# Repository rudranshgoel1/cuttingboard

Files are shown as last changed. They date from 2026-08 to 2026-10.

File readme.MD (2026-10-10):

# RP2040 Devboard
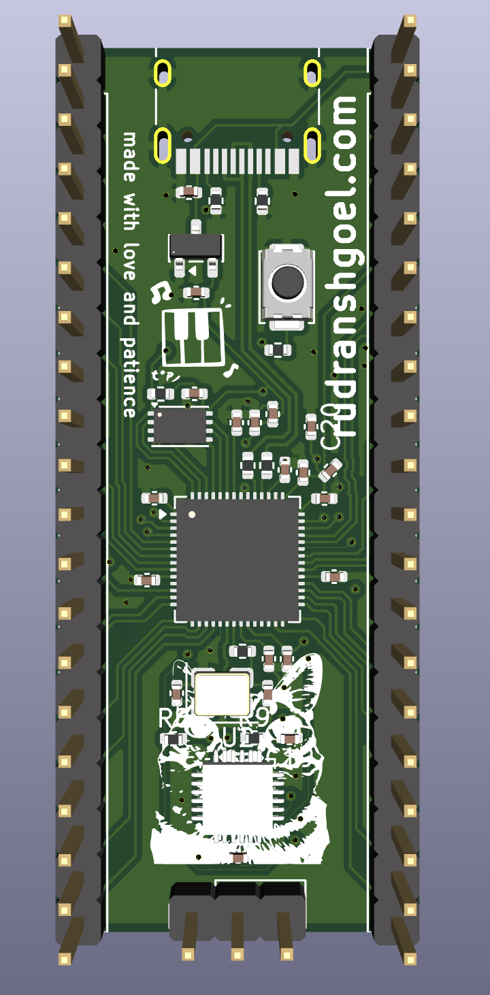
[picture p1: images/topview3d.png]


### Why did I make it?
bcz i need more hardware projects in my portfolio and also because it seemed like a fun hardware project which was not at all beginner friendly but still pretty interesting.

### What was the hardest part about this ?
routing. routing was hell. nevertheless, we did it.

### assembly?
going to hand solder each thing, if you want to do pcba (i can't due to budget reasons), go to the production folder and get the BOM and CPL for jlcpcb pcba service.

Features:

- rp2040 chip
- usb-c for power
- flash memory/storage
- crystal occilator
- built in accelerometer for cool shit
- Custom PCB Art (really cool)
- led

### Schematic
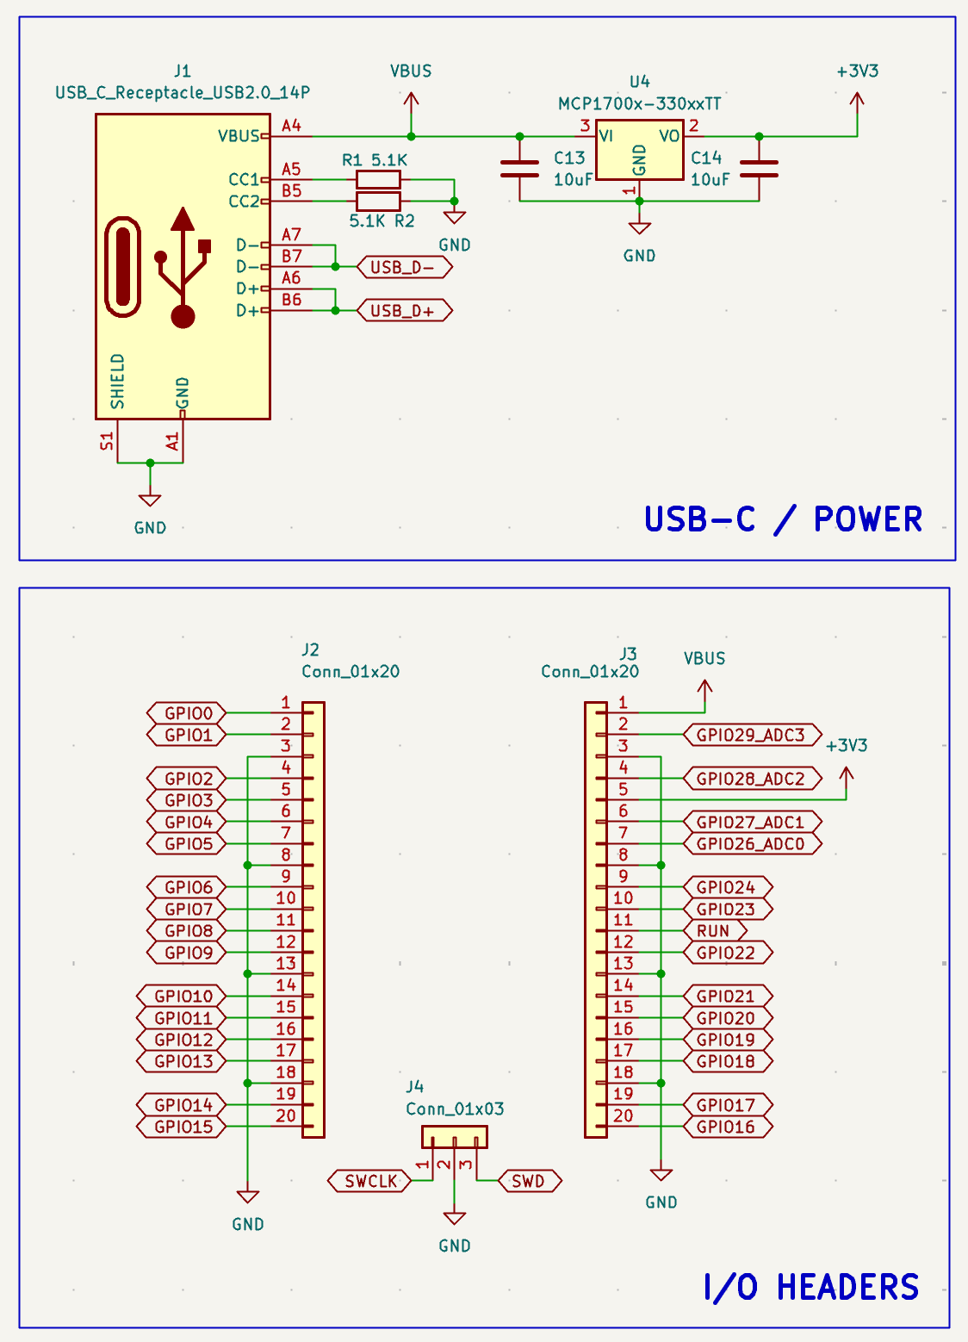
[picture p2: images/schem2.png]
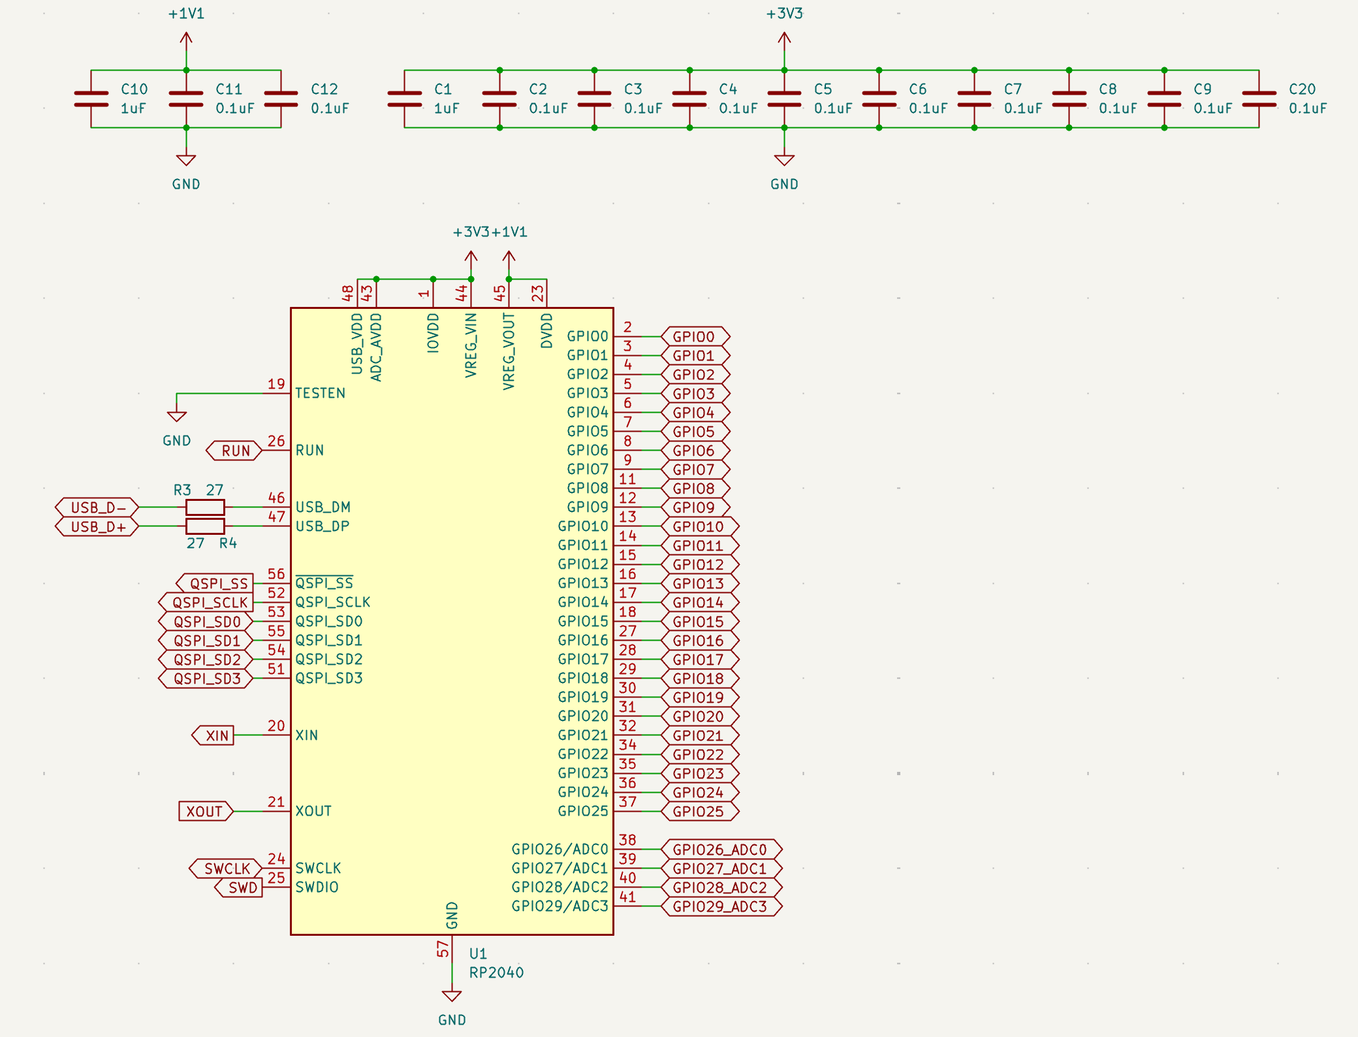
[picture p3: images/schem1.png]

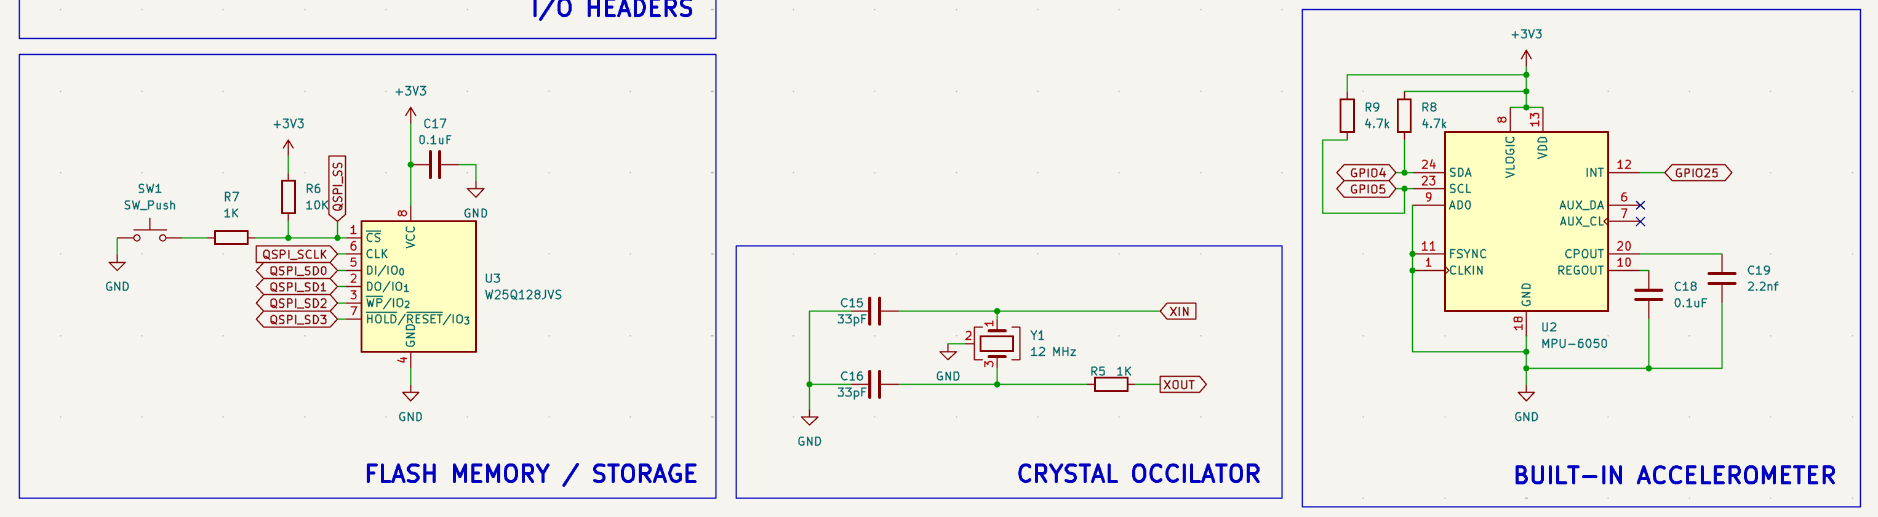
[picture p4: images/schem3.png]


### PCB 
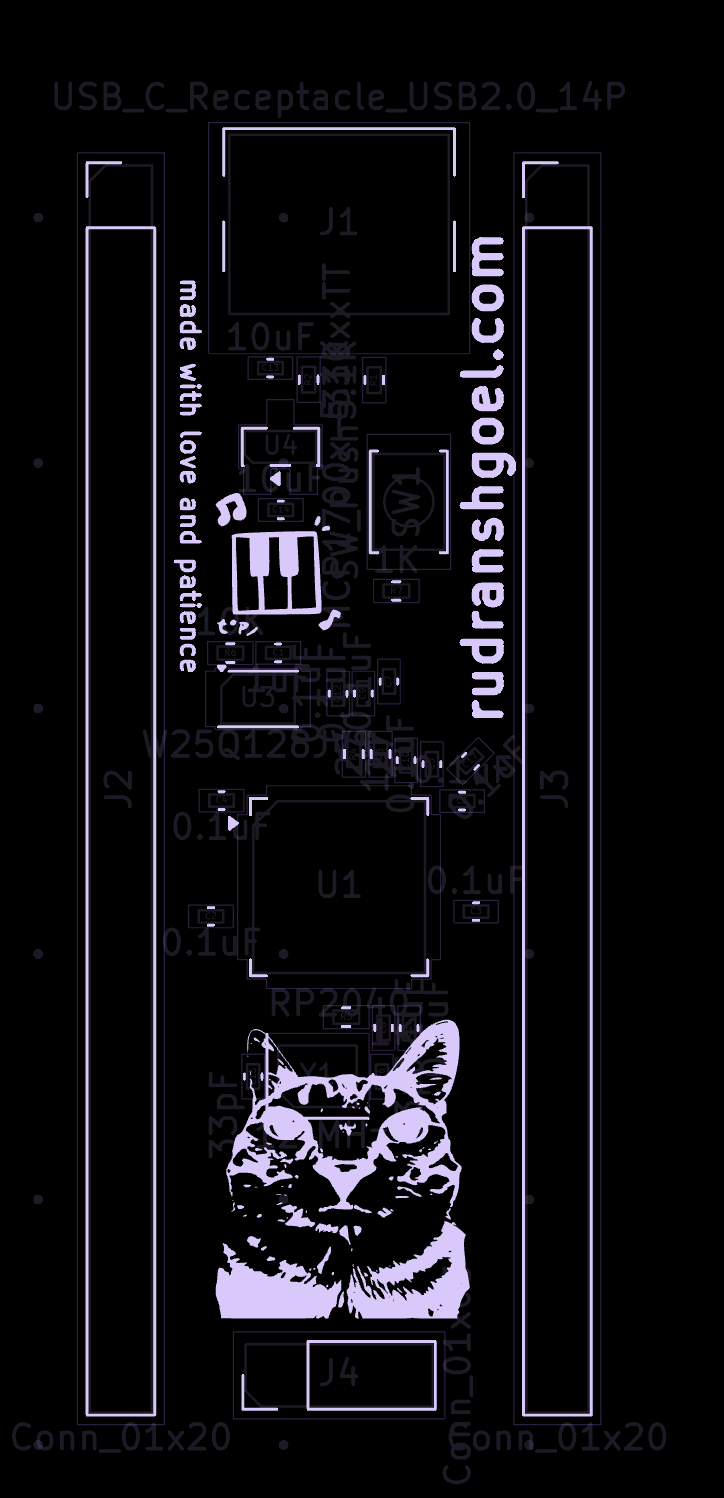
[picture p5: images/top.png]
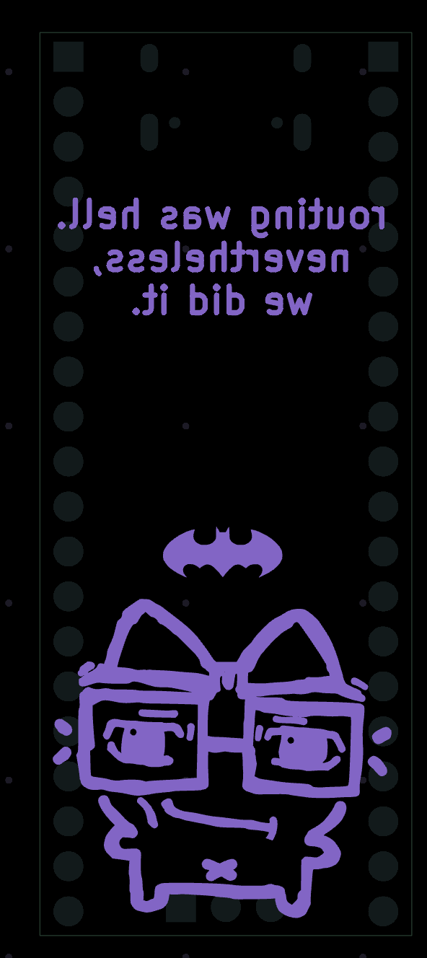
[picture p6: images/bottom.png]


### 3D view of all parts 
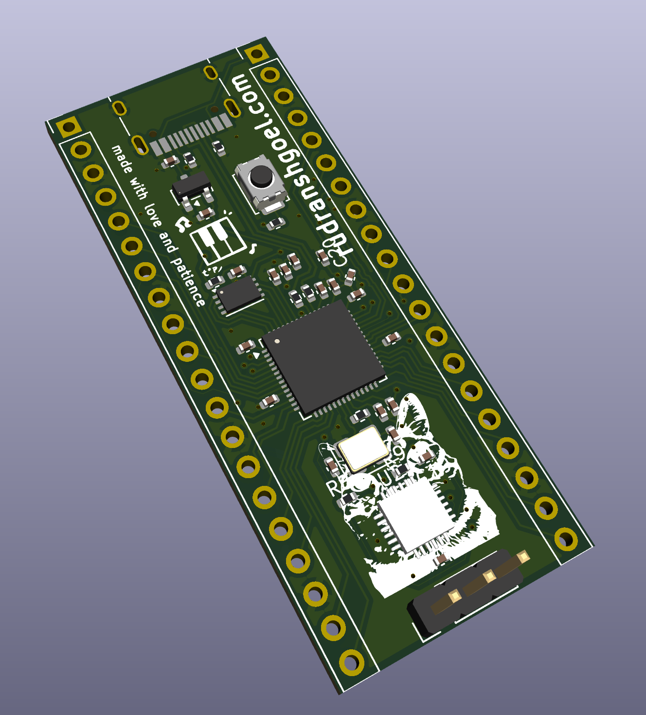
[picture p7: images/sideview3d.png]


## BOM

[BOM](BOM.csv)
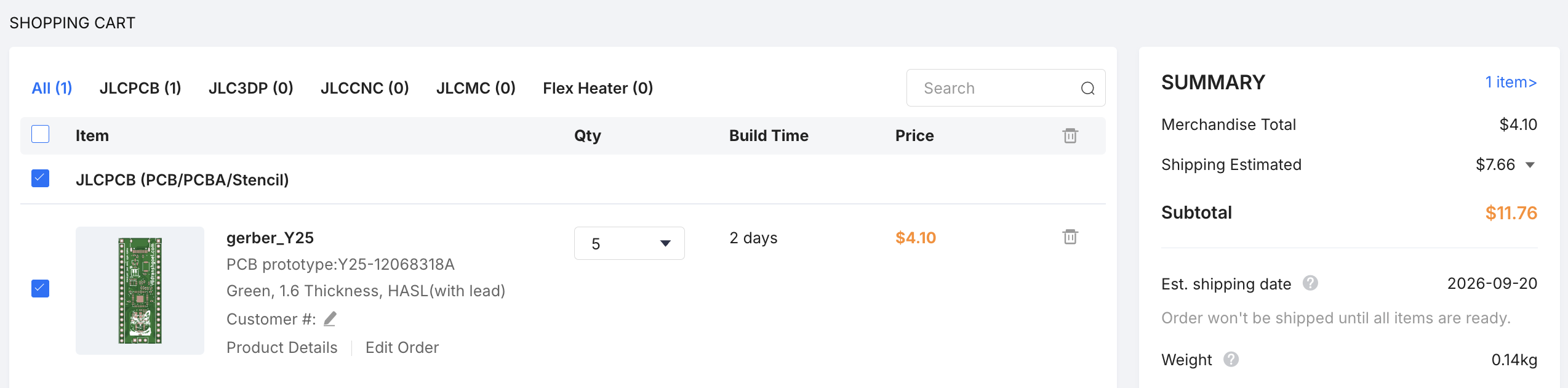
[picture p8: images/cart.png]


|Comment |Designator |Footprint |JLCPCB Part #|Price  |Source |
|---|---|---|---|---|---|
|1uF |C10,C1 |C_0402_1005Metric |C52923 |$0.2420|JLCPCB PCBA|
|MCP1700x-330xxTT |U4 |SOT-23 |C39051 |$2.0390|JLCPCB PCBA|
|33pF |C15,C16 |C_0402_1005Metric |C1562 |$0.1140|JLCPCB PCBA|
|1K |R7,R5 |R_0402_1005Metric |C11702 |$0.0780|JLCPCB PCBA|
|5.1K |R2,R1 |R_0402_1005Metric |C25905 |$0.0860|JLCPCB PCBA|
|12MHz |Y1 |Crystal_SMD_3225-4Pin_3.2x2.5mm |C9002 |$0.6629|JLCPCB PCBA|
|10uF |C13,C14 |C_0402_1005Metric |C19702 |$0.7000|JLCPCB PCBA|
|RP2040 |U1 |QFN-56-1EP_7x7mm_P0.4mm_EP3.2x3.2mm |C2040 |$4.9625|JLCPCB PCBA|
|0.1uF |C8,C17,C12,C4,C3,C5,C6,C2,C11,C7,C9|C_0402_1005Metric |C1525 |$0.3575|JLCPCB PCBA|
|W25Q128JVS |U3 |Winbond_USON-8-1EP_3x2mm_P0.5mm_EP0.2x1.6mm|C2843335 |$7.8700|JLCPCB PCBA|
|10K |R6 |R_0402_1005Metric |C25744 |$0.0380|JLCPCB PCBA|
|USB_C_Receptacle_USB2.0_14P|J1 |USB_C_Receptacle_HRO_TYPE-C-31-M-12 |C165948 |$0.9280|JLCPCB PCBA|
|27 |R4,R3 |R_0402_1005Metric |C25100 |$0.0704|JLCPCB PCBA|
|SW_Push |SW1 |SW_Push_SPST_NO_Alps_SKRK |C720477 |$0.5004|JLCPCB PCBA|

PCB Cost - $11.76 [ shipping included ]
Components Cost - $18.65

Final Price comes out to be 2,915.48 INR ($30.41)

## Total Pricing
(reviewers, i have a jlcpcb coupon for $15, so the pcb cost get's nullified, so the total cost for me is $18.65, but for others it would be the price given below)
The total price comes out to be 2,915.48 INR ($30.41) [ SHIPPING INCLUDED ]

I am going to hand solder all the components.

The pricing might slightly vary due to flash sales, and dollar market trends.

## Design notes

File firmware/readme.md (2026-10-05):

# firmware

- led on gpio0 blinks
- 500ms on and 500ms off

code is [here](firmware.ino)

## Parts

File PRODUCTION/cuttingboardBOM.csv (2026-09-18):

Id | Designator | Footprint | Quantity | Designation | Supplier and ref
1 | C1, C10 | C_0402_1005Metric | 2 | 1uF
2 | C2, C3, C4, C5, C6, C7, C8, C9, C11, C12, C17, C18, C20 | C_0402_1005Metric | 13 | 0.1uF
3 | C13, C14 | C_0402_1005Metric | 2 | 10uF
4 | C15, C16 | C_0402_1005Metric | 2 | 33pF
5 | C19 | C_0402_1005Metric | 1 | 2.2nf
6 | J1 | USB_C_Receptacle_HRO_TYPE-C-31-M-12 | 1 | USB_C_Receptacle_USB2.0_14P
7 | J2, J3 | PinHeader_1x20_P2.54mm_Vertical | 2 | Conn_01x20
8 | J4 | PinHeader_1x03_P2.54mm_Vertical | 1 | Conn_01x03
9 | R1, R2 | R_0402_1005Metric | 2 | 5.1K
10 | R3, R4 | R_0402_1005Metric | 2 | 27
11 | R5, R7 | R_0402_1005Metric | 2 | 1K
12 | R6 | R_0402_1005Metric | 1 | 10K
13 | R8, R9 | R_0402_1005Metric | 2 | 4.7k
14 | SW1 | SW_Push_SPST_NO_Alps_SKRK | 1 | SW_Push
15 | U1 | QFN-56-1EP_7x7mm_P0.4mm_EP3.2x3.2mm | 1 | RP2040
16 | U2 | InvenSense_QFN-24_4x4mm_P0.5mm | 1 | MPU-6050
17 | U3 | Winbond_USON-8-1EP_3x2mm_P0.5mm_EP0.2x1.6mm | 1 | W25Q128JVS
18 | U4 | SOT-23 | 1 | MCP1700x-330xxTT
19 | Y1 | Crystal_SMD_3225-4Pin_3.2x2.5mm | 1 | 12 MHz

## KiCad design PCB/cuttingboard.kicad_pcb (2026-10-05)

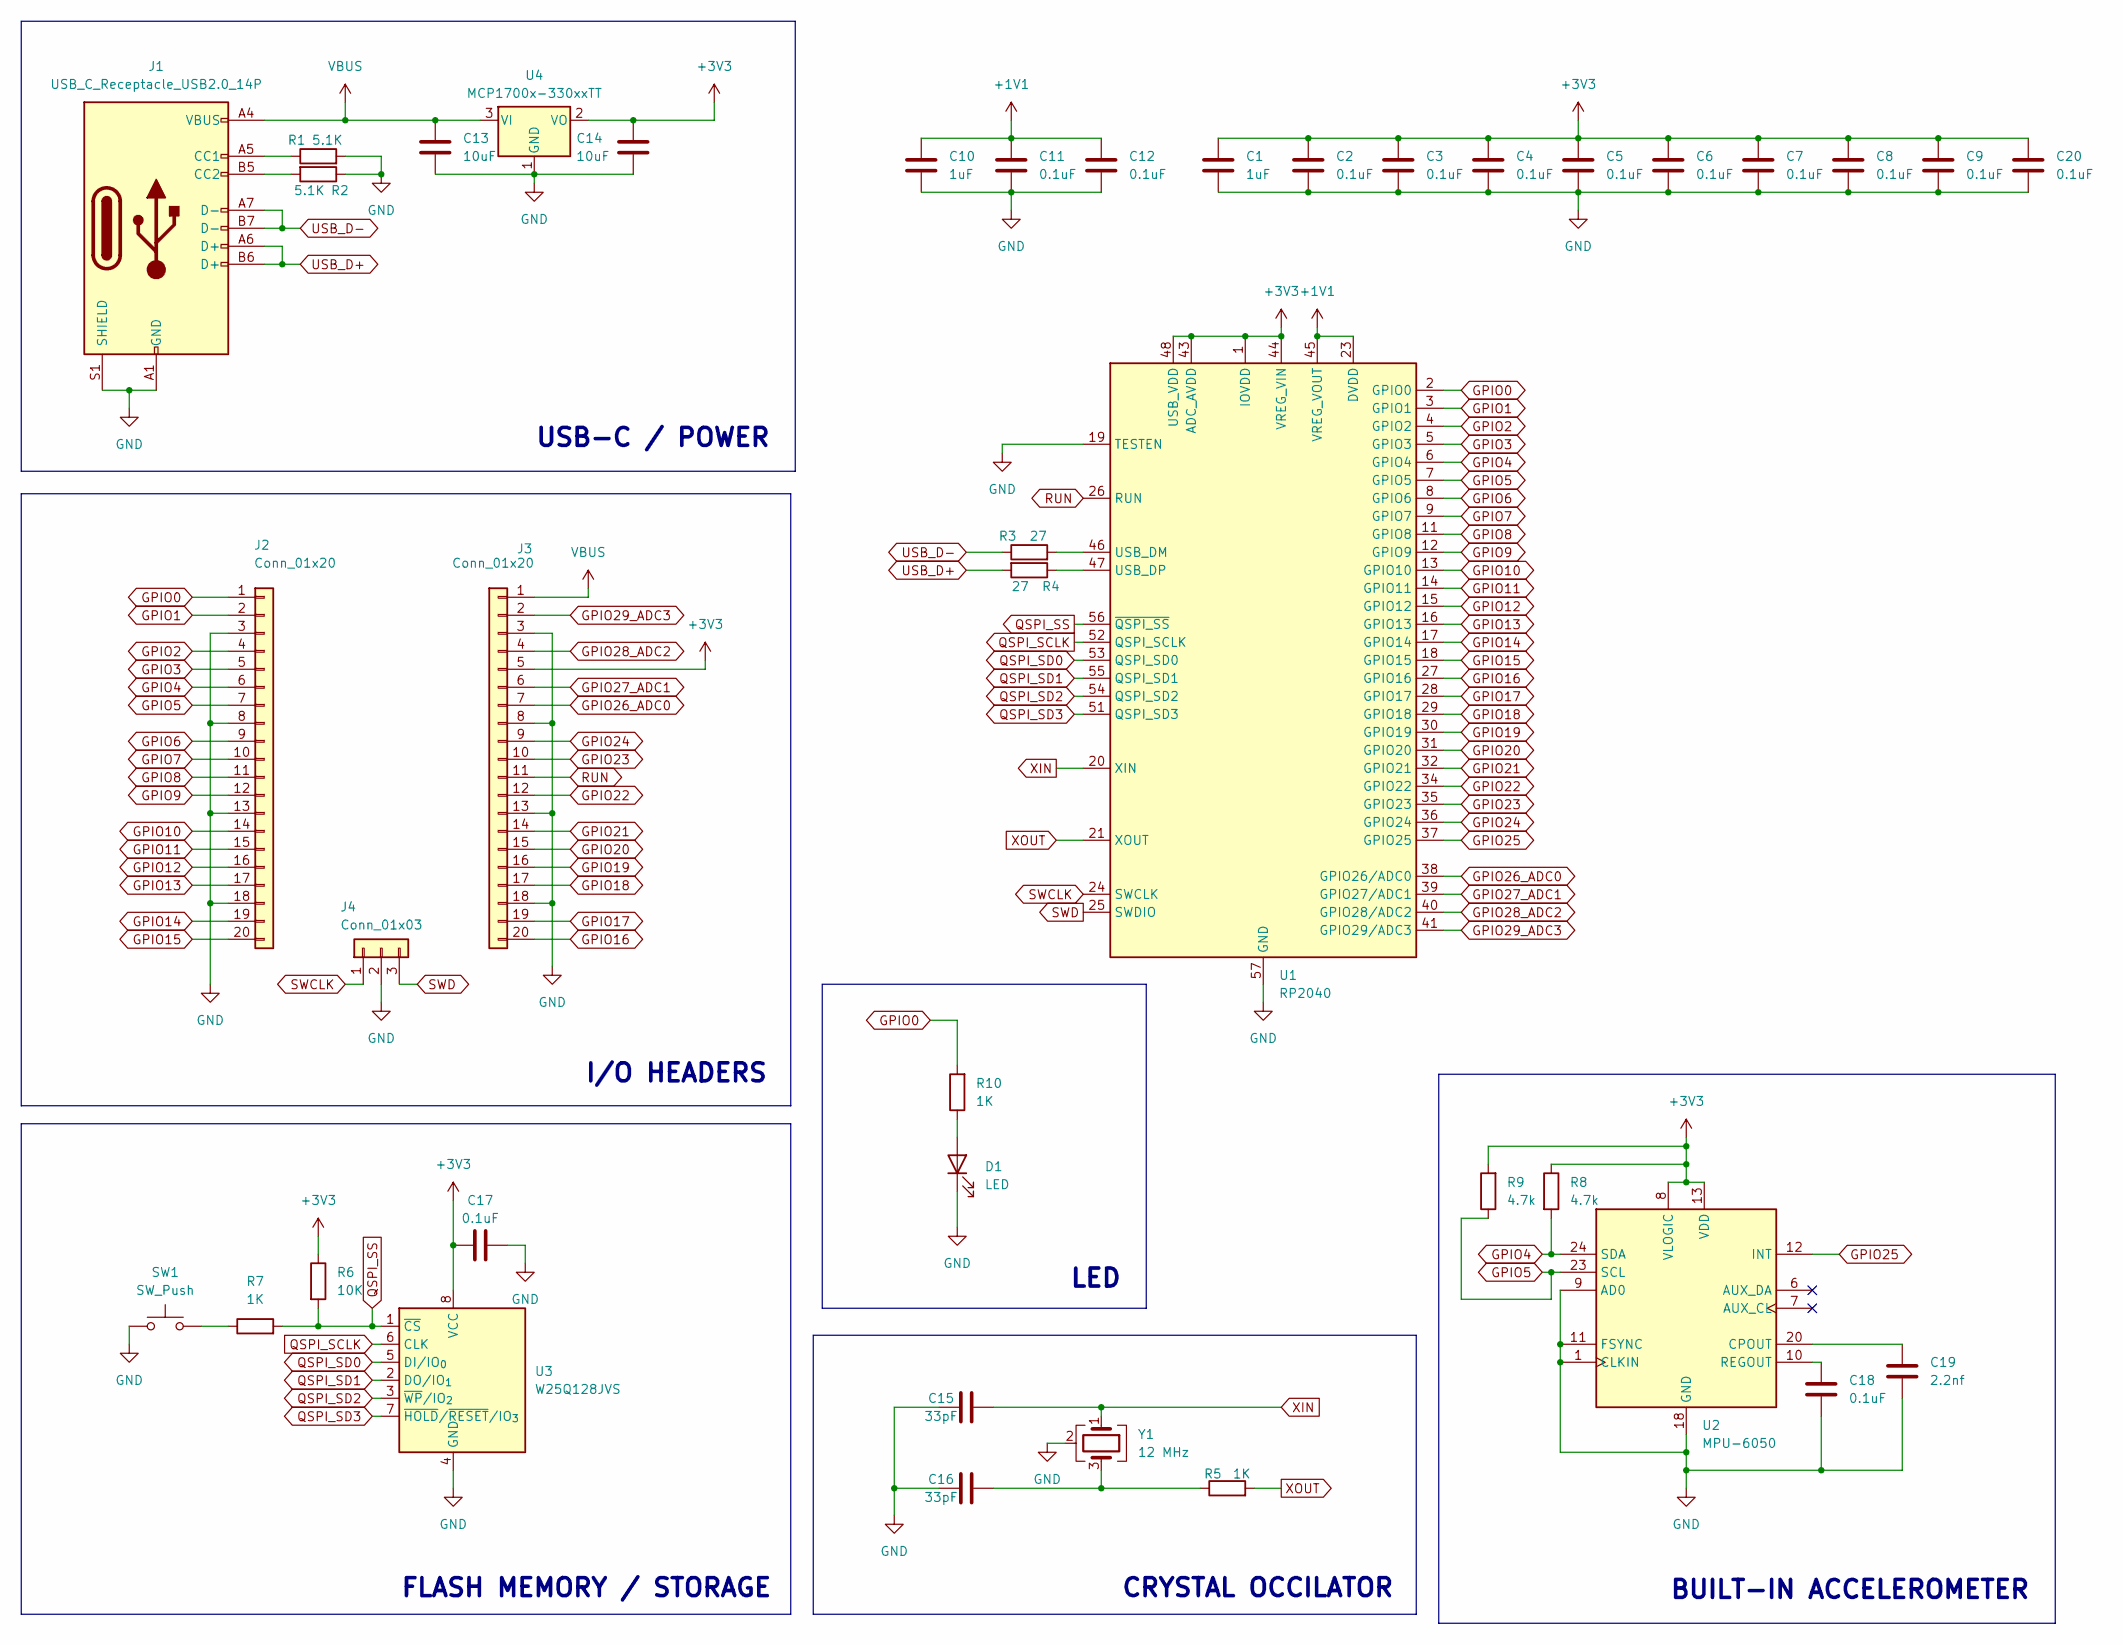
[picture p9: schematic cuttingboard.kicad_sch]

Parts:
C1, C10: 1uF; C_0402_1005Metric
C2, C3, C4, C5, C6, C7, C8, C9, C11, C12, C17, C18, C20: 0.1uF; C_0402_1005Metric
C13, C14: 10uF; C_0402_1005Metric
C15, C16: 33pF; C_0402_1005Metric
C19: 2.2nf; C_0402_1005Metric
D1: LED; LED_0805_2012Metric_Pad1.15x1.40mm_HandSolder
J1: USB_C_Receptacle_USB2.0_14P; USB_C_Receptacle_HRO_TYPE-C-31-M-12
J2, J3: Conn_01x20; PinHeader_1x20_P2.54mm_Vertical
J4: Conn_01x03; PinHeader_1x03_P2.54mm_Vertical
R1, R2: 5.1K; R_0402_1005Metric
R3, R4: 27; R_0402_1005Metric
R5, R7, R10: 1K; R_0402_1005Metric
R6: 10K; R_0402_1005Metric
R8, R9: 4.7k; R_0402_1005Metric
SW1: SW_Push; SW_Push_SPST_NO_Alps_SKRK
U1: RP2040; QFN-56-1EP_7x7mm_P0.4mm_EP3.2x3.2mm
U2: MPU-6050; InvenSense_QFN-24_4x4mm_P0.5mm
U3: W25Q128JVS; Winbond_USON-8-1EP_3x2mm_P0.5mm_EP0.2x1.6mm
U4: MCP1700x-330xxTT; SOT-23
Y1: 12 MHz; Crystal_SMD_3225-4Pin_3.2x2.5mm

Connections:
+1V1: C10.2, C11.2, C12.2, U1.23 (DVDD), U1.45 (VREG_VOUT), U1.50 (DVDD)
+3V3: C1.2, C2.2, C3.2, C4.2, C5.2, C6.2, C7.2, C8.2, C9.2, C14.1, C17.1, C20.2, J3.5, R6.1, R8.1, R9.2, U1.1 (IOVDD), U1.10 (IOVDD), U1.22 (IOVDD), U1.33 (IOVDD), U1.42 (IOVDD), U1.43 (ADC_AVDD), U1.44 (VREG_VIN), U1.48 (USB_VDD), U1.49 (IOVDD), U2.8 (VLOGIC), U2.13 (VDD), U3.8 (VCC), U4.2 (VO)
GND: C1.1, C2.1, C3.1, C4.1, C5.1, C6.1, C7.1, C8.1, C9.1, C10.1, C11.1, C12.1, C13.2, C14.2, C15.1, C16.1, C17.2, C18.1, C19.1, C20.1, D1.1 (K), J1.A1 (GND), J1.A12 (GND), J1.B1 (GND), J1.B12 (GND), J1.S1 (SHIELD), J2.3, J2.8, J2.13, J2.18, J3.3, J3.8, J3.13, J3.18, J4.2, R1.2, R2.1, SW1.1, U1.19 (TESTEN), U1.57 (GND), U2.1 (CLKIN), U2.9 (AD0), U2.11 (FSYNC), U2.18 (GND), U3.4 (GND), U4.1 (GND), Y1.2 (G), Y1.4 (G)
GPIO0: J2.1, R10.2, U1.2 (GPIO0)
GPIO1: J2.2, U1.3 (GPIO1)
GPIO2: J2.4, U1.4 (GPIO2)
GPIO3: J2.5, U1.5 (GPIO3)
GPIO4: J2.6, R8.2, U1.6 (GPIO4), U2.24 (SDA)
GPIO5: J2.7, R9.1, U1.7 (GPIO5), U2.23 (SCL)
GPIO6: J2.9, U1.8 (GPIO6)
GPIO7: J2.10, U1.9 (GPIO7)
GPIO8: J2.11, U1.11 (GPIO8)
GPIO9: J2.12, U1.12 (GPIO9)
GPIO10: J2.14, U1.13 (GPIO10)
GPIO11: J2.15, U1.14 (GPIO11)
GPIO12: J2.16, U1.15 (GPIO12)
GPIO13: J2.17, U1.16 (GPIO13)
GPIO14: J2.19, U1.17 (GPIO14)
GPIO15: J2.20, U1.18 (GPIO15)
GPIO16: J3.20, U1.27 (GPIO16)
GPIO17: J3.19, U1.28 (GPIO17)
GPIO18: J3.17, U1.29 (GPIO18)
GPIO19: J3.16, U1.30 (GPIO19)
GPIO20: J3.15, U1.31 (GPIO20)
GPIO21: J3.14, U1.32 (GPIO21)
GPIO22: J3.12, U1.34 (GPIO22)
GPIO23: J3.10, U1.35 (GPIO23)
GPIO24: J3.9, U1.36 (GPIO24)
GPIO25: U1.37 (GPIO25), U2.12 (INT)
GPIO26_ADC0: J3.7, U1.38 (GPIO26/ADC0)
GPIO27_ADC1: J3.6, U1.39 (GPIO27/ADC1)
GPIO28_ADC2: J3.4, U1.40 (GPIO28/ADC2)
GPIO29_ADC3: J3.2, U1.41 (GPIO29/ADC3)
unnamed: C16.2, R5.1, Y1.3
unnamed: D1.2 (A), R10.1
unnamed: J1.A5 (CC1), R1.1
unnamed: J1.B5 (CC2), R2.2
unnamed: R7.1, SW1.2
unnamed: R3.2, U1.46 (USB_DM)
unnamed: R4.1, U1.47 (USB_DP)
unnamed: C19.2, U2.20 (CPOUT)
unnamed: C18.2, U2.10 (REGOUT)
QSPI_SCLK: U1.52 (QSPI_SCLK), U3.6 (CLK)
QSPI_SD0: U1.53 (QSPI_SD0), U3.5 (DI/IO_{0})
QSPI_SD1: U1.55 (QSPI_SD1), U3.2 (DO/IO_{1})
QSPI_SD2: U1.54 (QSPI_SD2), U3.3 (~WP/IO_{2})
QSPI_SD3: U1.51 (QSPI_SD3), U3.7 (~HOLD/~RESET/IO_{3})
QSPI_SS: R6.2, R7.2, U1.56 (~QSPI_SS), U3.1 (~CS)
RUN: J3.11, U1.26 (RUN)
SWCLK: J4.1, U1.24 (SWCLK)
SWD: J4.3, U1.25 (SWDIO)
USB_D+: J1.A6 (D+), J1.B6 (D+), R4.2
USB_D-: J1.A7 (D-), J1.B7 (D-), R3.1
VBUS: C13.1, J1.A4 (VBUS), J1.A9 (VBUS), J1.B4 (VBUS), J1.B9 (VBUS), J3.1, U4.3 (VI)
XIN: C15.2, U1.20 (XIN), Y1.1
XOUT: R5.2, U1.21 (XOUT)

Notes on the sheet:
FLASH MEMORY / STORAGE
CRYSTAL OCCILATOR
LED
USB-C / POWER
I/O HEADERS
BUILT-IN ACCELEROMETER

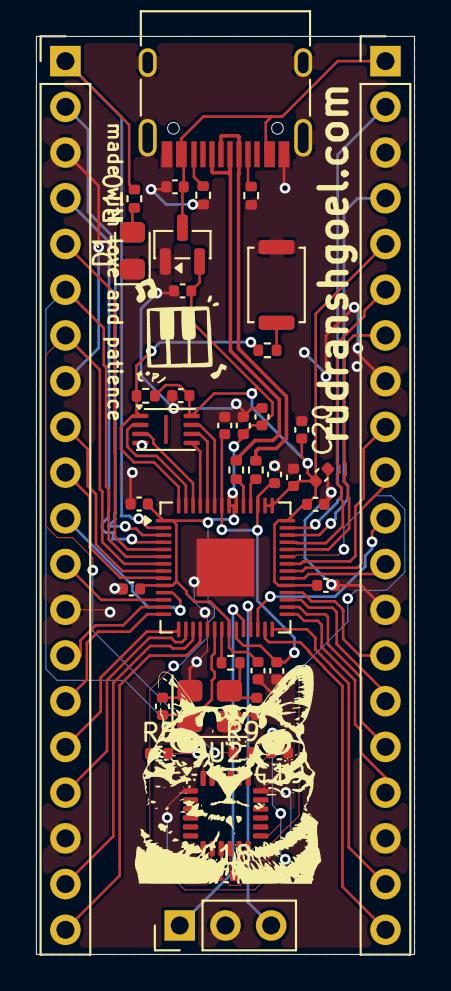
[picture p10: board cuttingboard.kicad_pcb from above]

Board: 2 copper layers, 21.0 x 51.0 mm, 41 parts (0 on the bottom side), 56 nets.

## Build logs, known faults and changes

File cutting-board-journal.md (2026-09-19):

---
title: "Cutting Board "
author: "stolen_username"
description: "a custom made rp2040 board"
created_at: "2026-08-25"
---

# 2026-09-18: Added an Accelerometer to make it more unique

**Total time spent: 1 hour 40 minutes**

so my devboard returned to me once again for almost being a replica of the tutorial, so i decided to add something unique

# what did i do?
- added mpu-6050 (accelerometer) in the devboard
- INT is connected to GPIO25 so that the rp2040 can talk with the accelerometer.
- controlling pins are GPIO4 and GPIO5 for the mpu-6050
- mentioned in the github readme that im going to hand solder this

schematic:


pcb:


# 2026-09-06: 1 minute

**Total time spent: 1 minute**

# what did i do?
- i decided im going to order the parts, and going to hand solder them.
- its going to be one in my aah for sure, but i guess its the most cheapest option i have.



# 2026-09-01: Updated BOM

**Total time spent: 5 minutes**

# what did i do?
- updated bom with item prices
- links are not there as they are chosen from the jlcpcb pcba option



# 2026-08-26: setup github repo + made bom and cpl

**Total time spent: 25 minutes**

# what did i work on?
- added gerber/bom/cpl files to the repo
- made the bom and cpl compatible for jlcpcb
- found the parts and selected them asper the jlcpcb library
- added the pcba finally to the cart (holy expensive)
- then made the readme.md for this
- then added journal to the repo
- then i hit ship ( i think its ready? )

no lapse for this coz i did this very very fast, but it GENUINELY TOOK ME 25 minutes coz why the hell are the names for the components so complicated and long???



# 2026-08-26: Silkscreen

**Total time spent: 21 minutes**

# what did i do?
- found some cool designs and set up the silkscreen.

lapse recording -> https://lapse.hackclub.com/timelapse/9ISGdCb-K3YG




( it is written "routing was hell. nevertheless, we did it." )

# 2026-08-26: completed the pcb

**Total time spent: 1 hour 53 minutes**

# what did i do?
- i have won, but at what cost?
- finally completed the routing (it was hell)
- first i completed setting up some leftover components
- then started the routing
- when i was routing, i had realised i had put some resistors in place of capacitors (on god im dumb)
- fixed those and got back to work
- routed the usb c
- routed the gpio pins to the gpio of the rp2040 chip
- routed the decoupling capacitors
- placed A LOT of vias
- spilled copper on the pcb coz im not covering the entire thing with a million vias
- it made a nice little net for gnd, so every gnd pin is connected to gnd, and every other is connected to their respective end
- some errors had come in the DRC (design rule checker if you didn't know (im sure u have)), checked that out and fixed those quickly
- and finally completed the routing and pcb was done finally.

lapse recording -> https://lapse.hackclub.com/timelapse/yU2to8uIAMKQ





# 2026-08-26: Started the routing + 50% pcb done (hurray)

**Total time spent: 38 minutes**

# what did i do?
- added all the decoupling capacitors
- it took me a solid minute to learn how to rotate an smd capacitor 45 deg
- also fun fact, i recorded the lapse when spain won the world cup

lapse recording -> https://lapse.hackclub.com/timelapse/5kd-ANLFqNg0



# 2026-08-26: Started the PCB for this monstrosity

**Total time spent: 33 minutes**

# what did i do?
- assigned the footprints
- opened the pcb editor (r we srs gng)
- positioned the gpio pins correctly (took me so long to figure out how it works)
- positioned the rp2040 chip and the usb c :p

lapse recording -> https://lapse.hackclub.com/timelapse/PoyksY5xZc1w



# 2026-08-25: Added Flash Storage + GPIO Pins and also added decoupling capacitors + schematic complete

**Total time spent: 32 minutes**

# what did i do?
- added flash storage
- added a button which would potentially load the devboard into bootsel mode (i think it is called that)
- added gpio pins which would go on the pcb (no shit)
- mapped those gpio with the rp2040 gpio
- added decoupling capacitors
- tidied up the schematic, it looks good now

lapse recording -> https://lapse.hackclub.com/timelapse/iEin5HjV4DM5




# 2026-08-25: Made the Project + Basic Schematic made

**Total time spent: 41 minutes**

# what did i work on?
- started the project (duh)
- made a basic schematic
- added the parts in the schematic editor and mapped only a few
- learned how usb c adapter works (wow)
- also learned about the ams 3.3v converter thing

lapse recording -> https://lapse.hackclub.com/timelapse/9J0623Afvo5e




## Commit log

2026-08-26 main commit
    [BOM.csv, BOM.xlsx, CuttingBoard - BOM File.csv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]
2026-09-01 BOM prices update and source
    [BOM.csv]
2026-09-18 updated devboard to new thing, added Accelerometer
    [BOM.xlsx, CuttingBoard - BOM File.csv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]
2026-10-05 added firmware and updated pcb files
    [cuttingboard.kicad_pcb, cuttingboard.kicad_sch]
2026-10-10 update readme with image formatting and add BOM details
